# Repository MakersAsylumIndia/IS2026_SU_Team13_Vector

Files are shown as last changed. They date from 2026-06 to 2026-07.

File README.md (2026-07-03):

# IS2026 SUMMER - PROJECT VECTOR
___

## Problem Statement
Tennis players, especially at the junior and recreational level, have no access to affordable, real-time feedback on their shot accuracy and reaction time during solo practice sessions, meaning weeks of training can go by with no objective measure of whether they are actually improving.
___

## Solution
Project Vector is a wall-mounted smart target system made up of 12 interactive pads arranged in a grid, each embedded with a piezoelectric sensor that detects the impact of a tennis ball and a WS2812B LED ring that lights up to indicate the target. An Arduino Mega processes all sensor inputs in real time, randomly activating pads one at a time and tracking whether the player hits the correct target within the time window, giving instant audio-visual feedback through colour-coded LEDs and a buzzer. The entire system is built from low-cost, off-the-shelf electronics and laser-cut components, making it affordable and replicable, while the firmware supports multiple game modes so players can train for pure accuracy, speed, or a combination of both.
___

## Additional Information
Project Vector started as a personal frustration — Vidyut trains tennis seriously and always felt that solo practice was essentially guesswork, hitting ball after ball with no real way to know if shot placement was getting better or just feeling better. That frustration turned into a question: could we build something that gives a player the kind of feedback a coach would give, but available any time, anywhere, without needing another person on the court?

The build itself happened at Makers Asylum Goa, where the team had five days to go from a concept and a box of components to a working wall-mounted system. A lot went wrong along the way — sensors that needed recalibrating, wiring that had to be redone, foam layers that didn't sit right — and honestly that process of breaking things and fixing them taught the team more than any project before it.

Looking ahead, the immediate goal is to add a small display that shows live session stats so a player can walk away knowing their accuracy percentage and average reaction time. Further down the line, the team wants to explore connecting the system to a simple app over WiFi using the ESP32, so players can track their improvement over weeks and months rather than just within a single session. The longer term dream is to make a version of this cheap enough and simple enough to install in school sports programmes across India, where access to quality sports coaching is limited but the desire to improve is very much there.
___

## TLDR
A wall-mounted smart tennis training system that lights up target pads, detects your hits in real time, and scores your accuracy and speed.
___

## License

Licenses

<a href="LICENSE.md">Open Source Licenses Facts</a>

#### Hardware
CERN Open Hardware License Version 2 - Strongly Reciprocal ([CERN-OHL-S-2.0](https://spdx.org/licenses/CERN-OHL-S-2.0.html)).

#### Software
MIT open source [license](http://opensource.org/licenses/MIT).

#### Documentation:
<br />This work is licensed under a <a rel="license" href="http://creativecommons.org/licenses/by/4.0/">Creative Commons Attribution 4.0 International License</a>.

---
## [OSHWA Certification](https://certification.oshwa.org/list.html)

[OSHW] IN000097 | Certified open source hardware | oshwa.org/cert

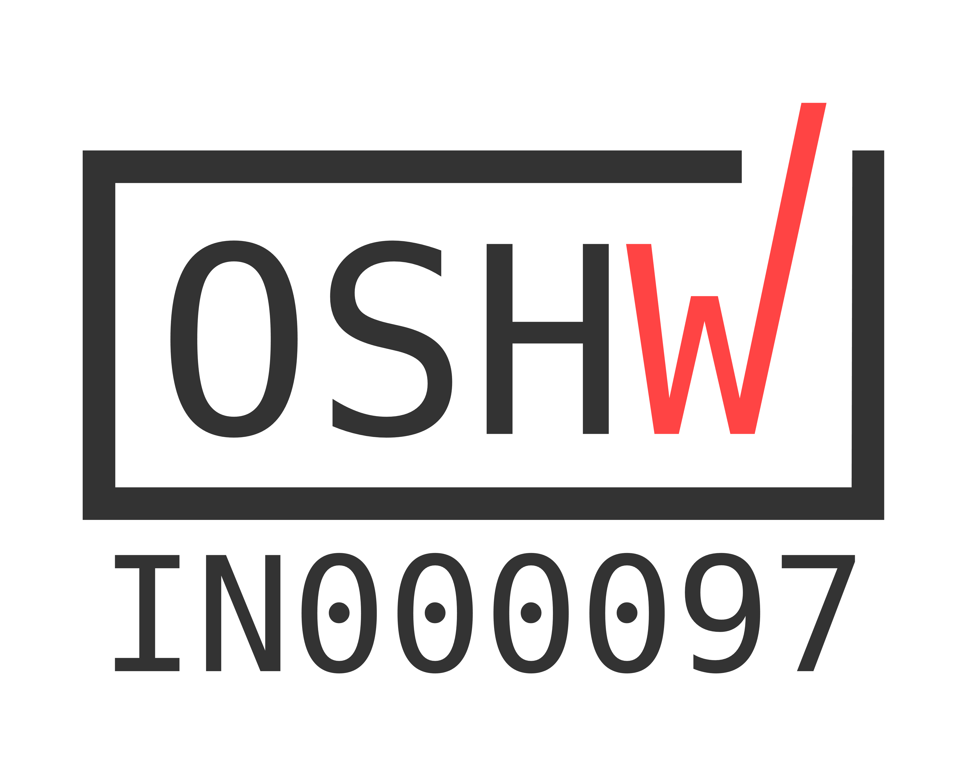
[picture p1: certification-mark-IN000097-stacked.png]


---

## 📬 Contact/Team

> _List team members and contact emails or GitHub profiles._
 
[Vidyut Sundar](https://github.com/vidyutsundar-cloud)

Anjali Randery

Saanvi Singh

[Maker's Asylum](https://github.com/MakersAsylumIndia)

---

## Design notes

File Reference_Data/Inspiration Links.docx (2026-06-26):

Links from which Project Vector came from:

1. Academic comparison paper (FitLight vs BlazePod vs XLiGHT) — the closest thing to a "report" you mentioned wanting: https://www.scitepress.org/PublishedPapers/2021/106779/106779.pdf
2. Reaction Training Dummy (Hackster.io) — 16-LED reaction trainer, closest maker precedent to your core mechanic: https://www.hackster.io/marijoblaz/reaction-training-dummy-6c8643
3. DIY HUNTER LED game (Hackster.io) — matches your score/timer/buzzer/timeout logic almost exactly: https://www.hackster.io/mircemk/diy-simple-hunter-led-game-with-arduino-18f21f
4. SparkFun Piezo Vibration Sensor Hookup Guide — the source for your exact 1MΩ resistor circuit: https://learn.sparkfun.com/tutorials/piezo-vibration-sensor-hookup-guide/all
5. BlazePod vs FitLight comparison (Gadgets & Wearables) — commercial product context and pricing: https://gadgetsandwearables.com/2020/12/06/blazepod-vs-fitlight/
6. Reactive Target Range - https://hackaday.com/2013/08/14/reactive-target-range-for-nerf-airsoft-etc/
7. Arduino Target Practise - https://www.instructables.com/Arduino-Target-Practice/
8. Bowl Buddy - https://www.makersasylum.com/project/bowl-buddy/

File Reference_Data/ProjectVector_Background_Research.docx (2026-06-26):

Background Research & Prior Work

Project Vector — Smart Shot Accuracy Tracker

Compiled from existing commercial products, academic comparisons, and maker-community projects

# Introduction

Project Vector is a twelve-pad, wall-mounted reaction and accuracy training system built around piezoelectric impact sensors and addressable RGB LED feedback rings. Before finalising its design, it is useful to understand where this idea sits relative to existing technology — both the commercial reaction-training products it resembles in function, and the maker-community electronics projects it resembles in construction. This document compiles findings from product reviews, an academic comparison paper, and several open hardware projects, organised around three questions: what already exists in this space, how is it typically built at the hobbyist level, and what does Project Vector do differently.

# The commercial reaction-training market

BlazePod, FitLight, and the wider reaction-light category

Reaction-light training systems are an established category in sports science and athletic conditioning, with the two best-known commercial products being BlazePod and FitLight. Both products consist of a set of independent wireless pods, each fitted with a touch-sensitive surface and a multicolour LED, that light up in a programmed or randomised sequence and deactivate when the athlete physically taps them. An academic comparison published at the 2021 International Conference on Sport Sciences Research and Technology Support evaluated FitLight, BlazePod, and a third Russian-made system called XLiGHT side by side, assessing usability, physical construction, and diagnostic capability across all three.

That comparison found that FitLight was generally judged more suitable for structured sport diagnostics, while BlazePod and XLiGHT were noted as more affordable, mass-market alternatives aimed at general fitness and team training rather than laboratory-grade measurement. This distinction matters for Project Vector's positioning: most existing systems either prioritise diagnostic precision at high cost, or affordability with comparatively simple touch-only sensing.

Pricing and accessibility in the existing market

Independent reviews consistently highlight cost as the main barrier to adoption for these systems. A six-pod FitLight kit has been priced at roughly €1,769 plus a separate carrying case, working out to around €295 per individual pod. BlazePod is positioned as the mid-range option, with a six-pod kit priced around €439, though mounting accessories such as wall adapters are sold separately and add meaningfully to the total cost if a athlete wants a fixed installation rather than floor-based pods.

A separate review noted that even at the BlazePod price point, the touch-sensitivity of the pods was sometimes inconsistent — requiring multiple taps to register a hit in some cases — which the reviewer found frustrating during competitive use against a training partner. This is a useful data point: even commercial, purpose-built reaction-training hardware does not perfectly solve the impact-detection reliability problem, suggesting that careful sensor calibration (rather than simply buying more expensive hardware) is the more important variable.

Activation methods: touch versus proximity versus impact

Reviews of both BlazePod and FitLight describe two broad activation methods used across the category: direct touch sensing, and proximity/motion sensing using infrared detection of a hand or object passing near the pod without contact. FitLight's higher-end hardware supports both modes, while base BlazePod kits are touch-only. Neither major commercial product appears to use piezoelectric impact sensing as its primary detection method — most rely on capacitive touch panels or infrared proximity detection instead.

This is one of the more useful findings from this research phase: Project Vector's choice of piezoelectric sensing is not the default approach used by the market leaders, but it is a well-documented and low-cost alternative within the maker electronics community, discussed further in Section 3. Piezoelectric sensing has the advantage of directly measuring impact force rather than mere proximity or surface contact, which is arguably a better fit for a tennis-ball-and-racket training context where the actual strike matters more than a light touch.

# Why reaction and accuracy training is trained this way

BlazePod's own published materials describe the underlying training rationale fairly directly: reaction training works by combining a visual stimulus with a required physical response, with the goal of reducing the time between perceiving a cue and executing a correct motor action. The company frames this as training the athlete to focus attention, filter distraction, and respond as quickly as possible to a randomised visual cue, which is functionally identical to what Project Vector's twelve-pad randomised activation pattern is designed to do.

This same source notes that reaction-training systems are commonly adapted to a wide range of sports by changing pad placement, activation sequencing, and required response (e.g. touch with a hand, foot, or piece of equipment such as a racket), rather than by changing the underlying hardware. This validates Project Vector's own design decision to keep the core sensor-and-LED hardware generic and place all the sport-specific logic (random pad selection, multi-pad activation sets, scoring rules) in software rather than in the physical build.

It is worth being precise about what is and is not established here. The broad training principle — pairing a randomised visual cue with a timed physical response to train reaction speed — is well documented across the commercial reaction-light category and is the same principle underlying classic sport-science reaction time testing. What is not independently verified in this research is a peer-reviewed efficacy study specific to a twelve-pad, piezo-based system; the academic source found (Section 2) is a comparative product analysis, not a controlled training-outcomes study. This distinction should be kept in mind if Project Vector's documentation makes any claims about measured improvement in athlete performance — the design rationale is well supported, but a specific performance claim would need its own dedicated study.

# Maker and hobbyist precedents

Piezoelectric sensing — the standard circuit

Within the hobbyist electronics community, interfacing a piezoelectric disc with a microcontroller is a well-trodden and consistently documented process. Multiple independent sources — including SparkFun's official hookup guide, the Arduino IDE's own built-in 'Knock' example sketch, and several independent tutorials — describe the same core circuit: one piezo lead connected to an analog input pin, the other to ground, with a resistor in the 470 kΩ to 1 MΩ range placed across the two leads.

The purpose of this resistor is described consistently across sources: it prevents the analog input pin from 'floating' (producing noisy, meaningless readings when no signal is present), and it limits the voltage spikes a piezo disc can generate under a hard, sudden impact, which could otherwise exceed the safe input range of the microcontroller's analog-to-digital converter. SparkFun's own oscilloscope testing found that with a 1 MΩ resistor in place, voltage spikes from a piezo disc stayed safely within roughly -0.5V to +5V, within the tolerable range for common microcontroller I/O pins.

This matches exactly the circuit already specified in Project Vector's own wiring documentation — a piezo disc with a parallel 1 MΩ resistor feeding a dedicated analog pin — which is reassuring confirmation that the project's electronics design follows established, low-risk practice rather than an untested approach.

Multi-target LED and impact-sensor games on Hackster.io

Several existing maker projects closely resemble Project Vector's core mechanic of a randomised lit target that the user must strike. One Hackster.io project, the 'Reaction Training Dummy,' was built specifically at a friend's request to create a cheap but effective reaction-training device, using sixteen LEDs arranged in pairs and switched via transistor, controlled by a single microcontroller.

That project notably chose a different impact-detection approach than Project Vector — it used TCRT5000 proximity sensors rather than piezoelectric discs, reasoning that ultrasonic sensors were too bulky and slow, while laser or time-of-flight sensors were comparatively expensive and harder to protect from dust in a hands-on training context. This is a useful contrast: it shows there is no single 'correct' sensing method in this space, and that the choice between piezo, proximity, and touch sensing involves a genuine trade-off between cost, response speed, durability, and ease of mounting — Project Vector's piezo-based choice optimises primarily for low cost and simple wiring at the expense of needing more careful per-channel threshold calibration.

Another closely related project, the 'DIY simple HUNTER LED game,' implements a moving-target light game across ten LEDs with a button, buzzer, and LCD display showing score and a countdown timer per level, ending the round and displaying a final score if the player fails to hit the active target within a fixed time window.

The structural similarity to Project Vector's own firmware logic is direct: both systems track an active target, enforce a timeout if the target is not struck in time, accumulate a score, and provide audible feedback through a buzzer on hit and game-over events. This is a strong sign that Project Vector's firmware design — written independently for this project — converges on the same general pattern that other hobbyists have already found to be a workable structure for this category of game, even though the underlying sensor technology (piezo impact versus proximity sensing) differs across these projects.

Addressable RGB LEDs as the visual feedback layer

Across the maker projects reviewed, simple single-colour LEDs (often just one LED per target, in 3mm or 5mm through-hole packages) are the more common visual feedback choice, generally because they are cheaper and require no special driver library. Project Vector's use of individually addressable WS2812B LED rings — twelve of them, each with multiple LEDs daisy-chained on a single data line — is a more capable approach than what is typical in beginner-level maker projects of this kind, since it allows for full-colour feedback (distinguishing an active target, a correct hit, and a wrong hit using entirely different colours on the same physical ring) without requiring additional wiring per colour channel. This is closer to the LED sophistication used in the commercial BlazePod and FitLight products, which use multicolour LEDs specifically so that colour itself can encode different training modes or feedback states.

# Where Project Vector sits relative to existing work

Drawing the above sources together, Project Vector can be reasonably described as occupying a specific gap between two existing categories. Commercial systems such as BlazePod and FitLight offer polished, app-connected, multicolour reaction training hardware, but at a price point — often several hundred euros for a handful of sensors — that puts a twelve-target system built the same way far out of reach for an independent or student project. Maker-community projects, on the other hand, regularly achieve similar core mechanics (randomised lit targets, score tracking, timeout-based misses) at low cost, but typically use simpler sensing methods (proximity, single-colour LEDs, smaller target counts of four to ten) than what Project Vector implements.

Project Vector's specific combination — twelve simultaneous targets, true piezoelectric force sensing rather than proximity or touch, and fully addressable multicolour LED rings per pad, all run from a single non-multiplexed microcontroller with sixteen native analog channels — does not appear to have an exact precedent in either the commercial or maker sources reviewed. The closest analogues are the academic light-sport-system comparison for the overall training concept, the SparkFun and Arduino piezo-interfacing documentation for the sensing circuit, and the Hackster.io reaction and target games for the game-logic structure. Project Vector's contribution, relative to this prior work, is combining a higher target count and true force sensing with full-colour feedback at a fraction of commercial system cost — closer in spirit to the maker tradition than the commercial product category, but built to a higher specification than most existing open hobbyist projects in this space.

# Summary

This research did not find a single existing project that is functionally identical to Project Vector. It did find strong, well-documented precedent for every individual component of the design: the piezo sensing circuit matches established hobbyist practice exactly, the randomised-target-with-timeout game logic matches patterns used in at least two comparable Hackster.io projects, and the overall training rationale (visual cue plus timed physical response to train reaction speed) matches the stated design philosophy of the two leading commercial products in this category. This suggests Project Vector is a reasonable and technically sound synthesis of existing ideas rather than an untested approach, while also identifying a genuine cost and specification gap — a twelve-target, piezo-sensed, full-colour system — that the sources reviewed here do not show being filled elsewhere at a comparable price point.

# References

[1] Ezhov, A., Zakharova, A. and Kachalov, D. "Modern Light Sport Training Systems: Critical Analysis of Their Construction and Performance Features." Proceedings of the 9th International Conference on Sport Sciences Research and Technology Support (icSPORTS 2021), pages 123–129. https://www.scitepress.org/PublishedPapers/2021/106779/106779.pdf

[2] "Reaction lights; what are they and is it worth buying?" Gymnastics Tools. https://gymnasticstools.com/reaction-lights-training/

[3] "BlazePod vs FitLight vs FitLight Jr: what's the difference?" Gadgets & Wearables. https://gadgetsandwearables.com/2020/12/06/blazepod-vs-fitlight/

[4] "5 reasons BlazePod is the ultimate reaction training platform." BlazePod. https://www.blazepod.com/blogs/all/5-reasons-blazepod-is-the-ultimate-reaction-training-platform

[5] "Piezo Vibration Sensor Hookup Guide." SparkFun Learn. https://learn.sparkfun.com/tutorials/piezo-vibration-sensor-hookup-guide/all

[6] "Arduino Piezoelectric Sensor Tutorial: Detect Taps, Vibrations, and Knocks (with Code)." ODG Electronics. https://www.origin-ic.com/blog/arduino-piezoelectric-sensor-tutorial-detect-taps-vibrations-and-knocks/49676

[7] Blažević, M. "Reaction Training Dummy." Hackster.io. https://www.hackster.io/marijoblaz/reaction-training-dummy-6c8643

[8] Pavleski, M. "DIY simple HUNTER LED game with Arduino." Hackster.io. https://www.hackster.io/mircemk/diy-simple-hunter-led-game-with-arduino-18f21f

Note: all sources above were retrieved via web search during the preparation of this document and reflect publicly available product reviews, one peer-reviewed conference paper, and open hobbyist project write-ups. Where a source is a product review or maker write-up rather than peer-reviewed research, it is presented as such — claims about training efficacy in this document are limited to what the cited sources themselves state, and no additional efficacy claims have been added.

Project Vector — Background Research

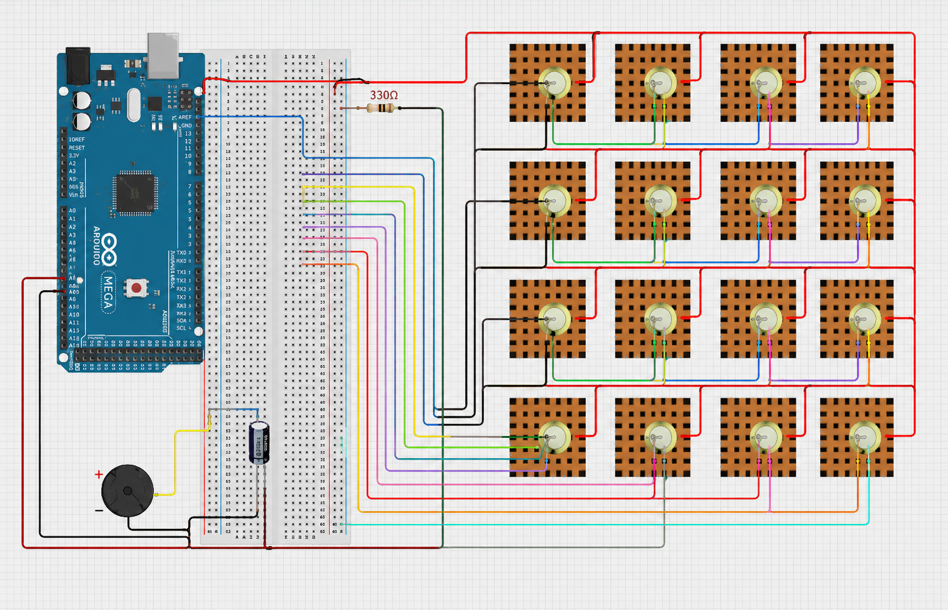
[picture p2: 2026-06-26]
Electronics/circuit_diagram_16_pads.png

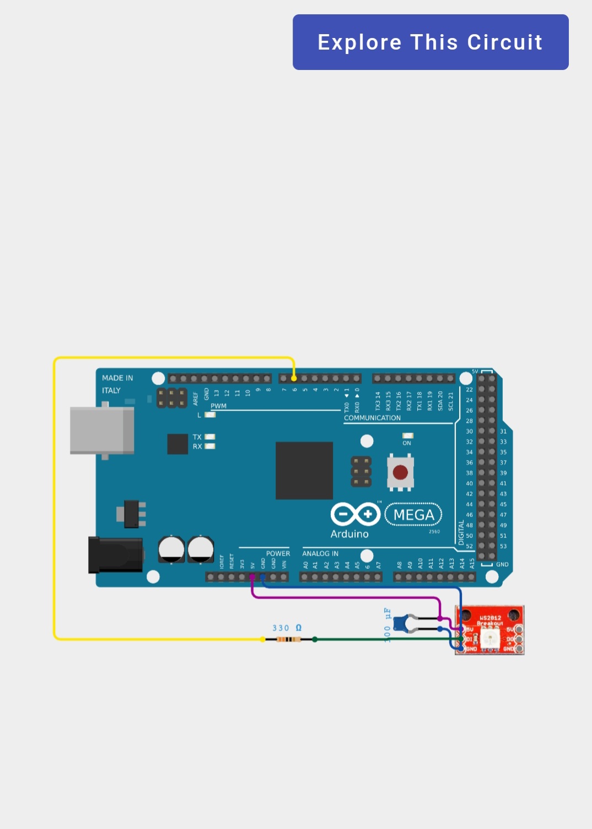
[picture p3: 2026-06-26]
Electronics/Circuit_Diagram_RGB Rings.jpg

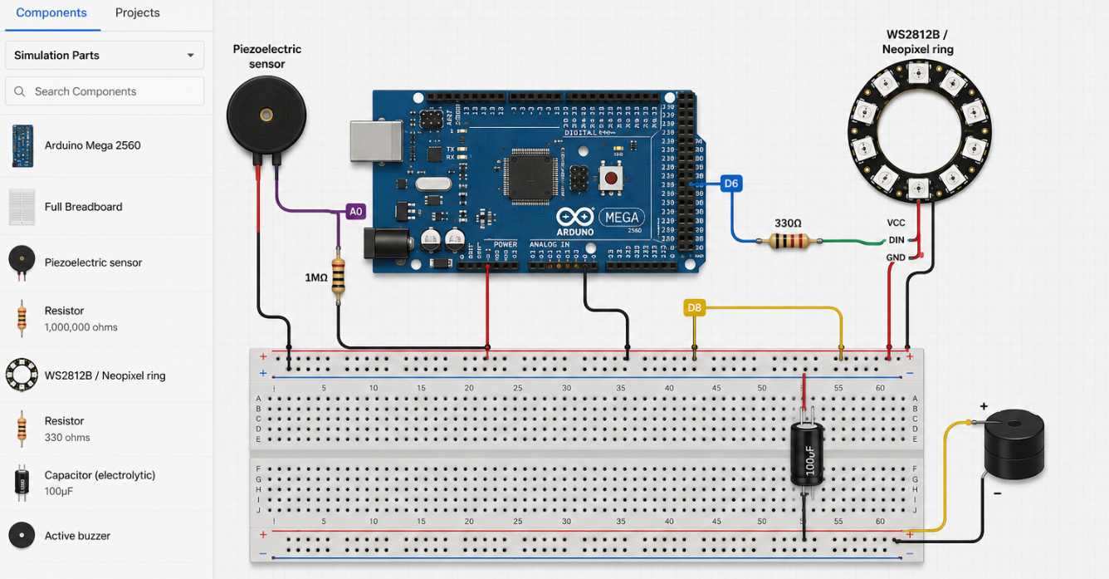
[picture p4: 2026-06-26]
Electronics/Circuit_Diagram_One_Pad.png

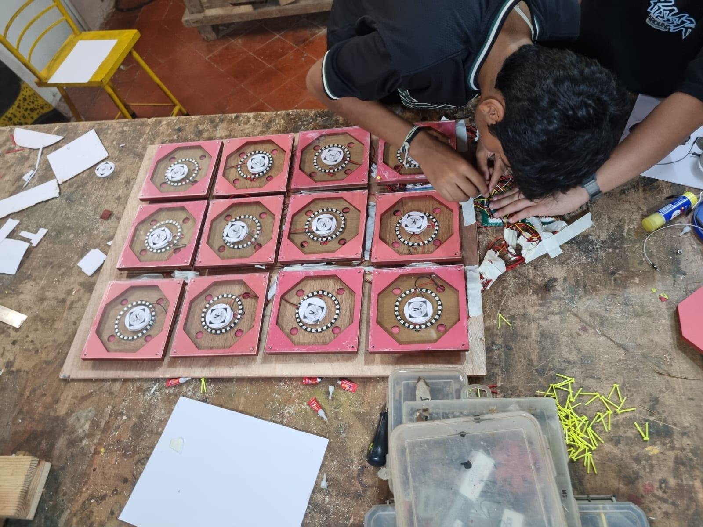
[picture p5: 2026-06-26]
Photos_Videos/Images/shared image (17).jpeg

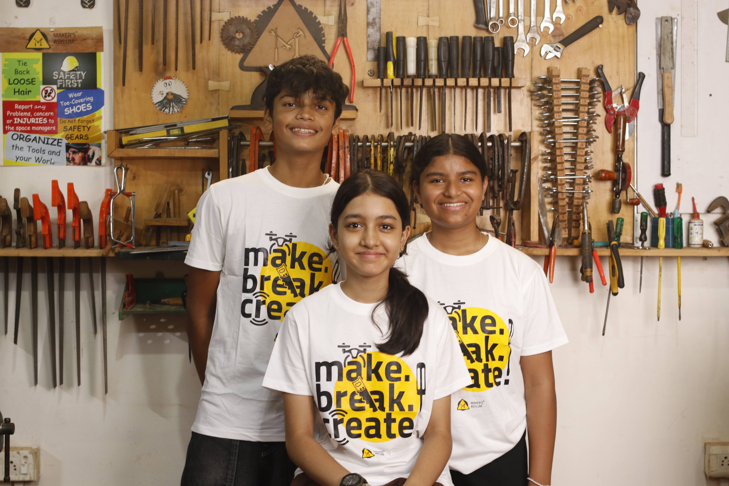
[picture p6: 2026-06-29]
Photos_Videos/Images/Team_Vector_02.jpg

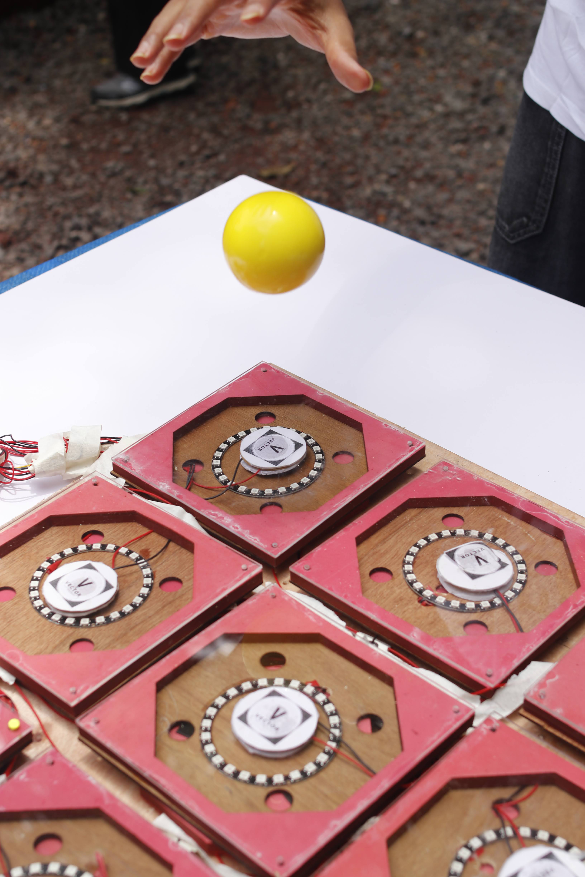
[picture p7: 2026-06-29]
Photos_Videos/Images/Team_Vector_06.jpg

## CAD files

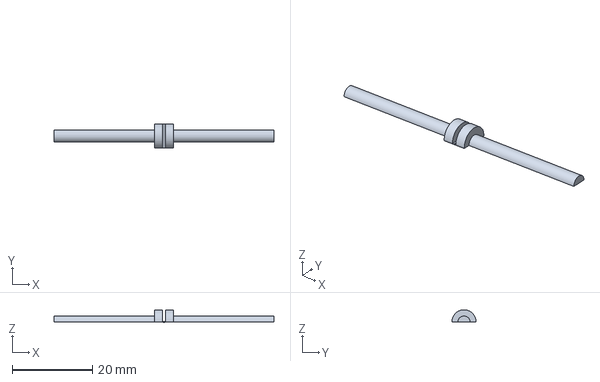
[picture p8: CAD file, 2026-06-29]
CAD/Unnamed.FCStd
54.8 x 6.00 x 3.10 mm

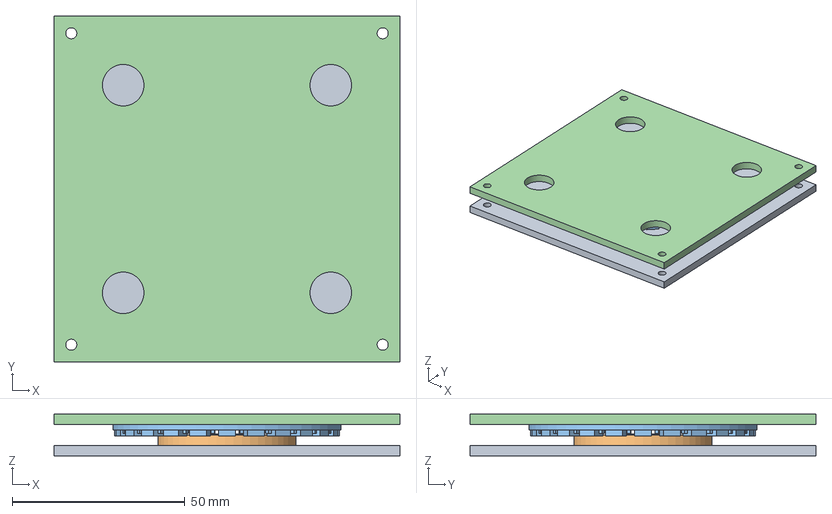
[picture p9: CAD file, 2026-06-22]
CAD/target_practise.FCStd
100.0 x 100.0 x 12.0 mm
Neopixel Ring 24 v13
Murata Piezo 7BB-15 v2

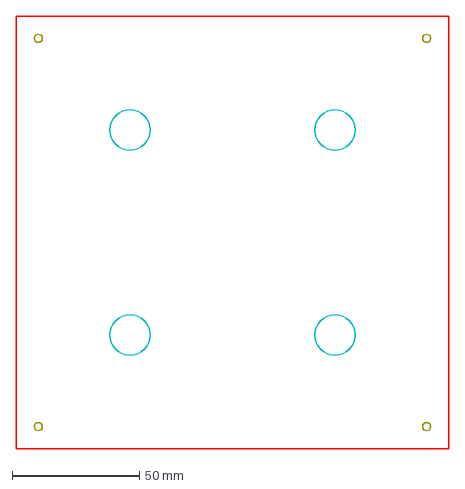
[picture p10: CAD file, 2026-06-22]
CAD/team_13_top_panel_FINAL.dxf
170.0 x 170.0 mm

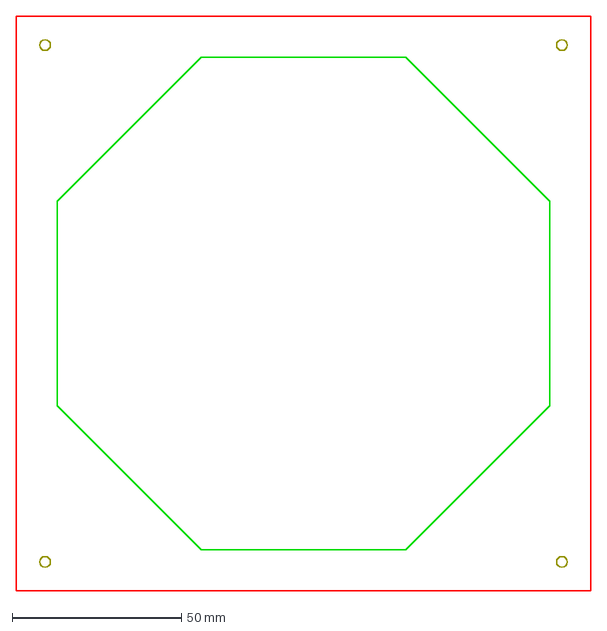
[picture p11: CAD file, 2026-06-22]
CAD/team_13_foam_octagon_FINAL.dxf
170.0 x 170.0 mm

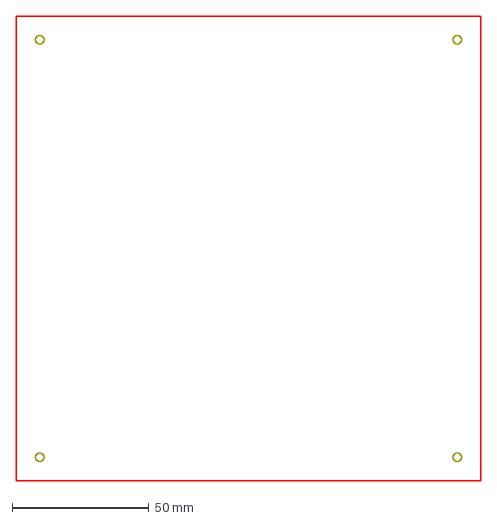
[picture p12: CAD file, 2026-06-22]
CAD/team_13_bottom_panel_FINAL.dxf
170.0 x 170.0 mm

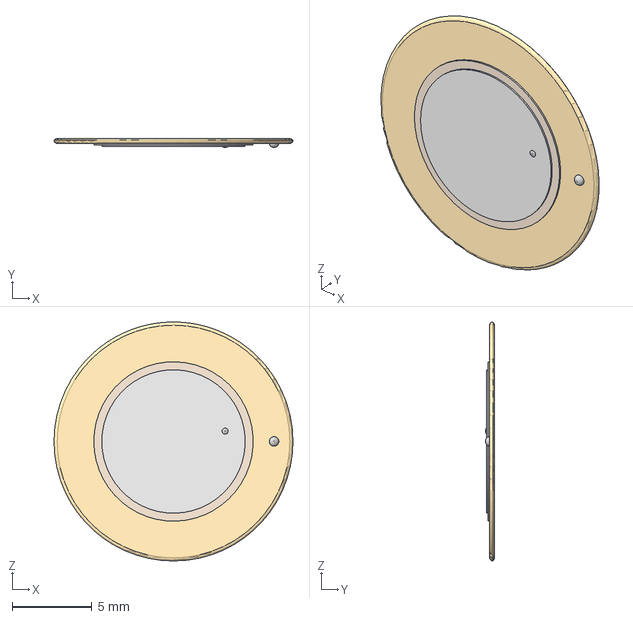
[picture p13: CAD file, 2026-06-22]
CAD/Murata Piezo 7BB-15 v2.step
15.0 x 0.55 x 15.0 mm

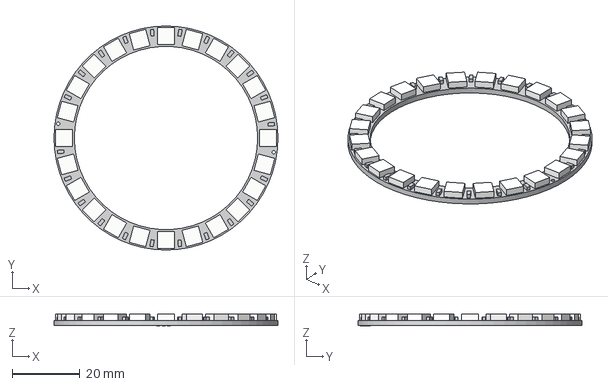
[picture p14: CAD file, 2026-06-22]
CAD/Neopixel Ring 24 v13.step
66.0 x 66.0 x 3.40 mm

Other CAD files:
CAD/push_pins.step
CAD/push_pins.FCStd

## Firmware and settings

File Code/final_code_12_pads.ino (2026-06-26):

// ============================================================
//  PROJECT VECTOR — Firmware FINAL (no buzzer, no button)
//  Arduino Mega 2560
//  12 pads · 24 LEDs per ring · 4 active at once
//  Piezos: A0–A11
//  LED data: pin 6 · LED power: 5V external
//  Game starts automatically after calibration
//  Game ends after 25 attempts then auto-restarts
// ============================================================

#include <Adafruit_NeoPixel.h>

#define LED_PIN  6

const int NUM_PADS      = 12;
const int LEDS_PER_RING = 24;
const int NUM_LEDS      = NUM_PADS * LEDS_PER_RING;
const int ACTIVE_COUNT  = 4;
const int TOTAL_ROUNDS  = 25;

const int piezoPins[NUM_PADS] = {
  A0, A1, A2,  A3,
  A4, A5, A6,  A7,
  A8, A9, A10, A11
};

#define BRIGHTNESS  60

int SPIKE_THRESHOLD = 80;
int DEBOUNCE_MS     = 300;

const unsigned long PAD_TIMEOUT_MS   = 4000;
const unsigned long RESTART_DELAY_MS = 3000;  // pause before auto-restart

int baseline[NUM_PADS];

Adafruit_NeoPixel strip(NUM_LEDS, LED_PIN, NEO_GRB + NEO_KHZ800);

uint32_t COL_TARGET;
uint32_t COL_HIT;
uint32_t COL_WRONG;
uint32_t COL_MISS;
uint32_t COL_GOLD;
uint32_t COL_OFF;

enum GameState { PLAYING, GAME_OVER_ANIM };
GameState state = PLAYING;

bool          activePads[NUM_PADS];
int           points        = 0;
int           totalHits     = 0;
int           totalAttempts = 0;
unsigned long padLitTime    = 0;
unsigned long lastHitTime[NUM_PADS];

void lightRing(int pad, uint32_t color) {
  int start = pad * LEDS_PER_RING;
  for (int i = 0; i < LEDS_PER_RING; i++)
    strip.setPixelColor(start + i, color);
}

void clearAll() { strip.clear(); strip.show(); }

void showActiveSet() {
  for (int p = 0; p < NUM_PADS; p++)
    lightRing(p, activePads[p] ? COL_TARGET : COL_OFF);
  strip.show();
}

void sendEvent(const char* type, int pad, int hits, int attempts, int pts) {
  Serial.print(type);
  Serial.print(","); Serial.print(pad);
  Serial.print(","); Serial.print(hits);
  Serial.print(","); Serial.print(attempts);
  Serial.print(","); Serial.println(pts);
}

void calibrateBaselines() {
  Serial.println("PV_CALIBRATING");
  // Blue sweep animation while calibrating
  for (int i = 0; i < NUM_LEDS; i++) {
    strip.setPixelColor(i, strip.Color(0, 30, 80));
    strip.show();
    delay(3);
  }
  for (int p = 0; p < NUM_PADS; p++) {
    long sum = 0;
    for (int s = 0; s < 100; s++) {
      sum += analogRead(piezoPins[p]);
      delay(5);
    }
    baseline[p] = sum / 100;
    Serial.print("PV_BASELINE,");
    Serial.print(p);
    Serial.print(",");
    Serial.println(baseline[p]);
  }
  clearAll();
  Serial.println("PV_CALIBRATED");
}

void activateNewSet() {
  memset(activePads, false, sizeof(activePads));
  int picked = 0;
  while (picked < ACTIVE_COUNT) {
    int c = random(0, NUM_PADS);
    if (!activePads[c]) { activePads[c] = true; picked++; }
  }
  padLitTime = millis();
  showActiveSet();
  int mask = 0;
  for (int p = 0; p < NUM_PADS; p++)
    if (activePads[p]) mask |= (1 << p);
  Serial.print("PV_ACTIVATE,");
  Serial.println(mask);
}

void gameOverSequence() {
  state = GAME_OVER_ANIM;
  clearAll();

  // Gold flash
  for (int f = 0; f < 4; f++) {
    for (int i = 0; i < NUM_LEDS; i++)
      strip.setPixelColor(i, COL_GOLD);
    strip.show();
    delay(250);
    clearAll();
    delay(120);
  }

  // Show results on rings: green = hits, red = misses
  for (int p = 0; p < NUM_PADS && p < totalHits; p++)
    lightRing(p, COL_HIT);
  for (int p = totalHits; p < NUM_PADS && p < totalAttempts; p++)
    lightRing(p, COL_MISS);
  strip.show();

  float accuracy = totalAttempts > 0
    ? (float)totalHits / totalAttempts * 100.0f : 0.0f;

  Serial.print("PV_END,");
  Serial.print(totalHits);     Serial.print(",");
  Serial.print(totalAttempts); Serial.print(",");
  Serial.print(points);        Serial.print(",");
  Serial.println(accuracy, 1);

  // Pause then auto-restart
  delay(RESTART_DELAY_MS);
  startGame();
}

void registerHit(int pad) {
  totalHits++;
  totalAttempts++;
  points += 10;
  lightRing(pad, COL_HIT);
  strip.show();
  sendEvent("PV_HIT", pad, totalHits, totalAttempts, points);
  delay(200);
  if (totalAttempts >= TOTAL_ROUNDS) { gameOverSequence(); return; }
  activateNewSet();
}

void registerWrongHit(int pad) {
  totalAttempts++;
  points = max(0, points - 5);
  lightRing(pad, COL_WRONG);
  strip.show();
  sendEvent("PV_WRONG", pad, totalHits, totalAttempts, points);
  delay(200);
  if (totalAttempts >= TOTAL_ROUNDS) { gameOverSequence(); return; }
  showActiveSet();
}

void registerMiss() {
  totalAttempts++;
  for (int p = 0; p < NUM_PADS; p++)
    if (activePads[p]) lightRing(p, COL_MISS);
  strip.show();
  sendEvent("PV_MISS", -1, totalHits, totalAttempts, points);
  delay(300);
  if (totalAttempts >= TOTAL_ROUNDS) { gameOverSequence(); return; }
  activateNewSet();
}

void startGame() {
  state         = PLAYING;
  points        = 0;
  totalHits     = 0;
  totalAttempts = 0;
  memset(activePads, false, sizeof(activePads));
  for (int i = 0; i < NUM_PADS; i++) lastHitTime[i] = 0;
  Serial.println("PV_START");
  activateNewSet();
}

void setup() {
  Serial.begin(115200);
  Serial.println("PV_BOOT");

  strip.begin();
  strip.setBrightness(BRIGHTNESS);
  strip.show();

  COL_TARGET = strip.Color(0,   80,  255);
  COL_HIT    = strip.Color(0,   255, 80);
  COL_WRONG  = strip.Color(255, 100, 0);
  COL_MISS   = strip.Color(255, 0,   0);
  COL_GOLD   = strip.Color(255, 200, 0);
  COL_OFF    = strip.Color(0,   0,   0);

  randomSeed(analogRead(A12));

  // Calibrate then start immediately
  calibrateBaselines();
  startGame();
}

void loop() {
  if (state == PLAYING) {
    if (millis() - padLitTime > PAD_TIMEOUT_MS) {
      registerMiss();
      return;
    }
    for (int pad = 0; pad < NUM_PADS; pad++) {
      int raw   = analogRead(piezoPins[pad]);
      int delta = raw - baseline[pad];
      bool pastDebounce = (millis() - lastHitTime[pad]) > (unsigned long)DEBOUNCE_MS;
      if (delta > SPIKE_THRESHOLD && pastDebounce) {
        lastHitTime[pad] = millis();
        if (activePads[pad]) registerHit(pad);
        else                 registerWrongHit(pad);
        return;
      }
    }
  }
}

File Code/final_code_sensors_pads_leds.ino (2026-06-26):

#include <Adafruit_NeoPixel.h>

#define STRIP_A_PIN 18
#define STRIP_B_PIN 19
#define NUM_LEDS_A 141
#define NUM_LEDS_B 58

Adafruit_NeoPixel stripA(NUM_LEDS_A, STRIP_A_PIN, NEO_GRB + NEO_KHZ800);
Adafruit_NeoPixel stripB(NUM_LEDS_B, STRIP_B_PIN, NEO_GRB + NEO_KHZ800);

const int piezoPins[14] = {
  32, 33, 34, 35, 36,
  39, 25, 26, 27, 14,
  12, 13, 4, 15
};

const int threshold = 1500;

// Format: {A_start1, A_end1, A_start2, A_end2, B_start1, B_end1, B_start2, B_end2}
const int tileToLEDRanges[15][8] = {
  {12, 18, 19, 29, 1, 3, 4, 6},     // Tile 0
  {23, 29, 61, 67, 6, 9, 10, 12},   // Tile 1
  {61, 71, 72, 80, 12, 15, 16, 18}, // Tile 2
  {112, 117, 74, 80, 18, 20, 21, 24}, // Tile 3
  {112, 117, 118, 128, 24, 26, 27, 29}, // Tile 4
  {106, 111, 129, 134, 24, 29, 30, 35}, // Tile 5
  {80, 85, 106, 111, 18, 24, 35, 31}, // Tile 6
  {55, 60, 80, 85, 12, 18, 41, 47}, // Tile 7
  {30, 35, 55, 61, 6, 12, 47, 53}, // Tile 8
  {6, 12, 30, 35, 1, 6, 54, 58},   // Tile 9
  {1, 6, 36, 43, 54, 56, 57, 58},  // Tile 10
  {36, 43, 44, 55, 47, 50, 51, 53}, // Tile 11
  {49, 54, 87, 93, 41, 45, 46, 47}, // Tile 12
  {87, 95, 96, 105, 35, 37, 38, 41}, // Tile 13
  {100, 105, 135, 141, 29, 33, 34, 35}  // Tile 14
};

const int targetTileIndex = 7;  // << Set this manually to the tile you want the bowler to hit (0 to 14)

void setup() {
  Serial.begin(115200);
  for (int i = 0; i < 14; i++) pinMode(piezoPins[i], INPUT);

  stripA.begin(); stripA.show();
  stripB.begin(); stripB.show();

  // Light only the target tile in blue
  clearAllTiles();
  lightUpTile(targetTileIndex, 0, 0, 255);  // Blue
  stripA.show();
  stripB.show();
}

void lightUpRange(Adafruit_NeoPixel &strip, int start, int end, uint32_t color) {
  for (int i = start; i <= end; i++) {
    if (i >= 0 && i < strip.numPixels()) strip.setPixelColor(i, color);
  }
}

void lightUpTile(int tileIndex, uint8_t r, uint8_t g, uint8_t b) {
  if (tileIndex < 0 || tileIndex >= 15) return;
  uint32_t color = stripA.Color(r, g, b);
  lightUpRange(stripA, tileToLEDRanges[tileIndex][0], tileToLEDRanges[tileIndex][1], color);
  lightUpRange(stripA, tileToLEDRanges[tileIndex][2], tileToLEDRanges[tileIndex][3], color);
  lightUpRange(stripB, tileToLEDRanges[tileIndex][4], tileToLEDRanges[tileIndex][5], color);
  lightUpRange(stripB, tileToLEDRanges[tileIndex][6], tileToLEDRanges[tileIndex][7], color);
}

void clearAllTiles() {
  for (int i = 0; i < stripA.numPixels(); i++) stripA.setPixelColor(i, 0, 0, 0);
  for (int i = 0; i < stripB.numPixels(); i++) stripB.setPixelColor(i, 0, 0, 0);
}

void loop() {
  int maxValue = 0, hitIndex = -1;

  for (int i = 0; i < 14; i++) {
    int sensorValue = analogRead(piezoPins[i]);
    if (sensorValue > maxValue) {
      maxValue = sensorValue;
      hitIndex = i;
    }
  }

  if (maxValue > threshold && hitIndex != -1) {
    if (hitIndex == 12 || hitIndex == 13) hitIndex++;  // Adjust for missing index
    int square = hitIndex + 1;
    Serial.print("Ball has bounced on square ");
    Serial.println(square);

    clearAllTiles();

    if (hitIndex == targetTileIndex) {
      lightUpTile(hitIndex, 0, 255, 0);  // Green if hit target
    } else {
      lightUpTile(targetTileIndex, 255, 0, 0); // Red for missed target
      lightUpTile(hitIndex, 255, 0, 0);       // Red for wrong hit
    }

    stripA.show();
    stripB.show();

    delay(1000);  // Show result briefly

    // Reset
    clearAllTiles();
    lightUpTile(targetTileIndex, 0, 0, 255);  // Blue target again
    stripA.show();
    stripB.show();
  }

  delay(10);
}

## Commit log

2026-06-22 added CAD files for one module of the matrix
    [target_practise.FCStd]
2026-06-29 added project photos
    [Unnamed.FCStd, push_pins.FCStd, push_pins.step]
